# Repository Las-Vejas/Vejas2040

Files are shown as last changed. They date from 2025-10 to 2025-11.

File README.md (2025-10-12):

# Vejas2040
an RP2040 devboard made by me

What it includes:
- RP2040
- 1 Neopixel LED
- 2 buttons
- a pico form factor

Here are some images of the board (3d files):

SCR-20251012-igse
SCR-20251012-igog
SCR-20251012-igli

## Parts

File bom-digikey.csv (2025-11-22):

Manufacturer Part Number | Manufacturer Name | Description | Requested Quantity 1 | Pack Type 1 | Digi-Key Part Number 1 | Unit Price 1 | Total Price | Reference Designator
JMK105BJ105KV-F | Taiyo Yuden | CAP CER 1UF 6.3V X5R 0402 | 10 | Cut Tape (CT) | 587-1231-1-ND | 0.00500 | $0.05 | C1,C10
CL05A104KA5NNNC | Samsung Electro-Mechanics | CAP CER 0.1UF 25V X5R 0402 | 70 | Cut Tape (CT) | 1276-1043-1-ND | 0.00200 | $0.14 | C2,C3,C4,C5,C6,C7,C8,C9,C11,C12,C17,C18
CL10A106MP8NNNC | Samsung Electro-Mechanics | CAP CER 10UF 10V X5R 0603 | 10 | Cut Tape (CT) | 1276-1871-1-ND | 0.01700 | $0.17 | C13,C14
CL05C330JB5NNNC | Samsung Electro-Mechanics | CAP CER 33PF 50V C0G/NP0 0402 | 10 | Cut Tape (CT) | 1276-1272-1-ND | 0.00300 | $0.03 | C15,C16
DX07S016JA1R1500 | JAE Electronics | CONN RCP USB2.0 TYP C 24P SMD RA | 5 | Cut Tape (CT) | 670-DX07S016JA1R1500CT-ND | 1.67000 | $8.35 | J1
ERA-2AEB512X | Panasonic Electronic Components | RES SMD 5.1K OHM 0.1% 1/16W 0402 | 10 | Cut Tape (CT) | P5.1KDCCT-ND | 0.08200 | $0.82 | R1,R2
RC0402FR-0727R4L | YAGEO | RES 27.4 OHM 1% 1/16W 0402 | 10 | Cut Tape (CT) | YAG3085CT-ND | 0.00700 | $0.07 | R3,R4
RC0402JR-071KL | YAGEO | RES 1K OHM 5% 1/16W 0402 | 15 | Cut Tape (CT) | 311-1.0KJRCT-ND | 0.00600 | $0.09 | R5,R7,R8
RC0402JR-0710KL | YAGEO | RES 10K OHM 5% 1/16W 0402 | 10 | Cut Tape (CT) | 311-10KJRCT-ND | 0.00600 | $0.06 | R6
SKRKAHE020 | Alps Alpine | SWITCH TACTILE SPST-NO 0.05A 12V | 10 | Cut Tape (CT) | 4809-SKRKAHE020CT-ND | 0.35100 | $3.51 | SW1,SW2
SC0914(13) | Raspberry Pi | IC MCU 32BIT EXT MEM 56QFN | 5 | Cut Tape (CT) | 2648-SC0914(13)CT-ND | 0.70000 | $3.50 | U1
W25Q128JVSIQ TR | Winbond Electronics | IC FLASH 128MBIT SPI/QUAD 8SOIC | 5 | Cut Tape (CT) | 256-W25Q128JVSIQTRCT-ND | 1.85000 | $9.25 | U3
MCP1700T-3302E/TT | Microchip Technology | IC REG LINEAR 3.3V 250MA SOT23-3 | 5 | Cut Tape (CT) | MCP1700T3302ETTCT-ND | 0.51000 | $2.55 | U4
ABM8-272-T3 | Abracon LLC | CRYSTAL 12.0000MHZ 10PF SMD | 5 | Cut Tape (CT) | 535-ABM8-272-T3CT-ND | 0.66000 | $3.30 | Y1

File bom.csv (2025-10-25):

Item | Price
PCB | $9.10
Digikey | $31.87
JLC Shipping | $18.35
TOTAL | $59.32

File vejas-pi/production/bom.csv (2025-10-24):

Designator | Footprint | Quantity | Value | LCSC Part #
C1, C10 | 0402 | 2 | 1uF
C11, C12, C17, C18, C2, C3, C4, C5, C6, C7, C8, C9 | 0402 | 12 | 0.1uF
C13, C14 | 0603 | 2 | 10uF
C15, C16 | 0402 | 2 | 33pF
D2 | LED_WS2812B-2020_PLCC4_2.0x2.0mm | 1 | WS2812B-2020
J1 | USB_C_Receptacle_JAE_DX07S016JA1R1500 | 1 | USB_C_Receptacle_USB2.0_14P
J2, J3 | PinHeader_1x20_P2.54mm_Vertical | 2 | Conn_01x20_Pin
R1, R2 | 0402 | 2 | 5.1K
R3, R4 | 0402 | 2 | 27.4
R5, R7, R8 | 0402 | 3 | 1K
R6 | 0402 | 1 | 10K
SW1, SW2 | SW_Push_SPST_NO_Alps_SKRK | 2 | SW_Push
U1 | QFN-56-1EP_7x7mm_P0.4mm_EP3.2x3.2mm | 1 | RP2040
U2 | LGA-16_3x3mm_P0.5mm_LayoutBorder3x5y | 1 | LIS3DH
U3 | Winbond_USON-8-1EP_3x2mm_P0.5mm_EP0.2x1.6mm | 1 | W25Q128JVS
U4 | SOT-23 | 1 | MCP1700x-330xxTT
Y1 | Crystal_SMD_3225-4Pin_3.2x2.5mm | 1 | 12MHz

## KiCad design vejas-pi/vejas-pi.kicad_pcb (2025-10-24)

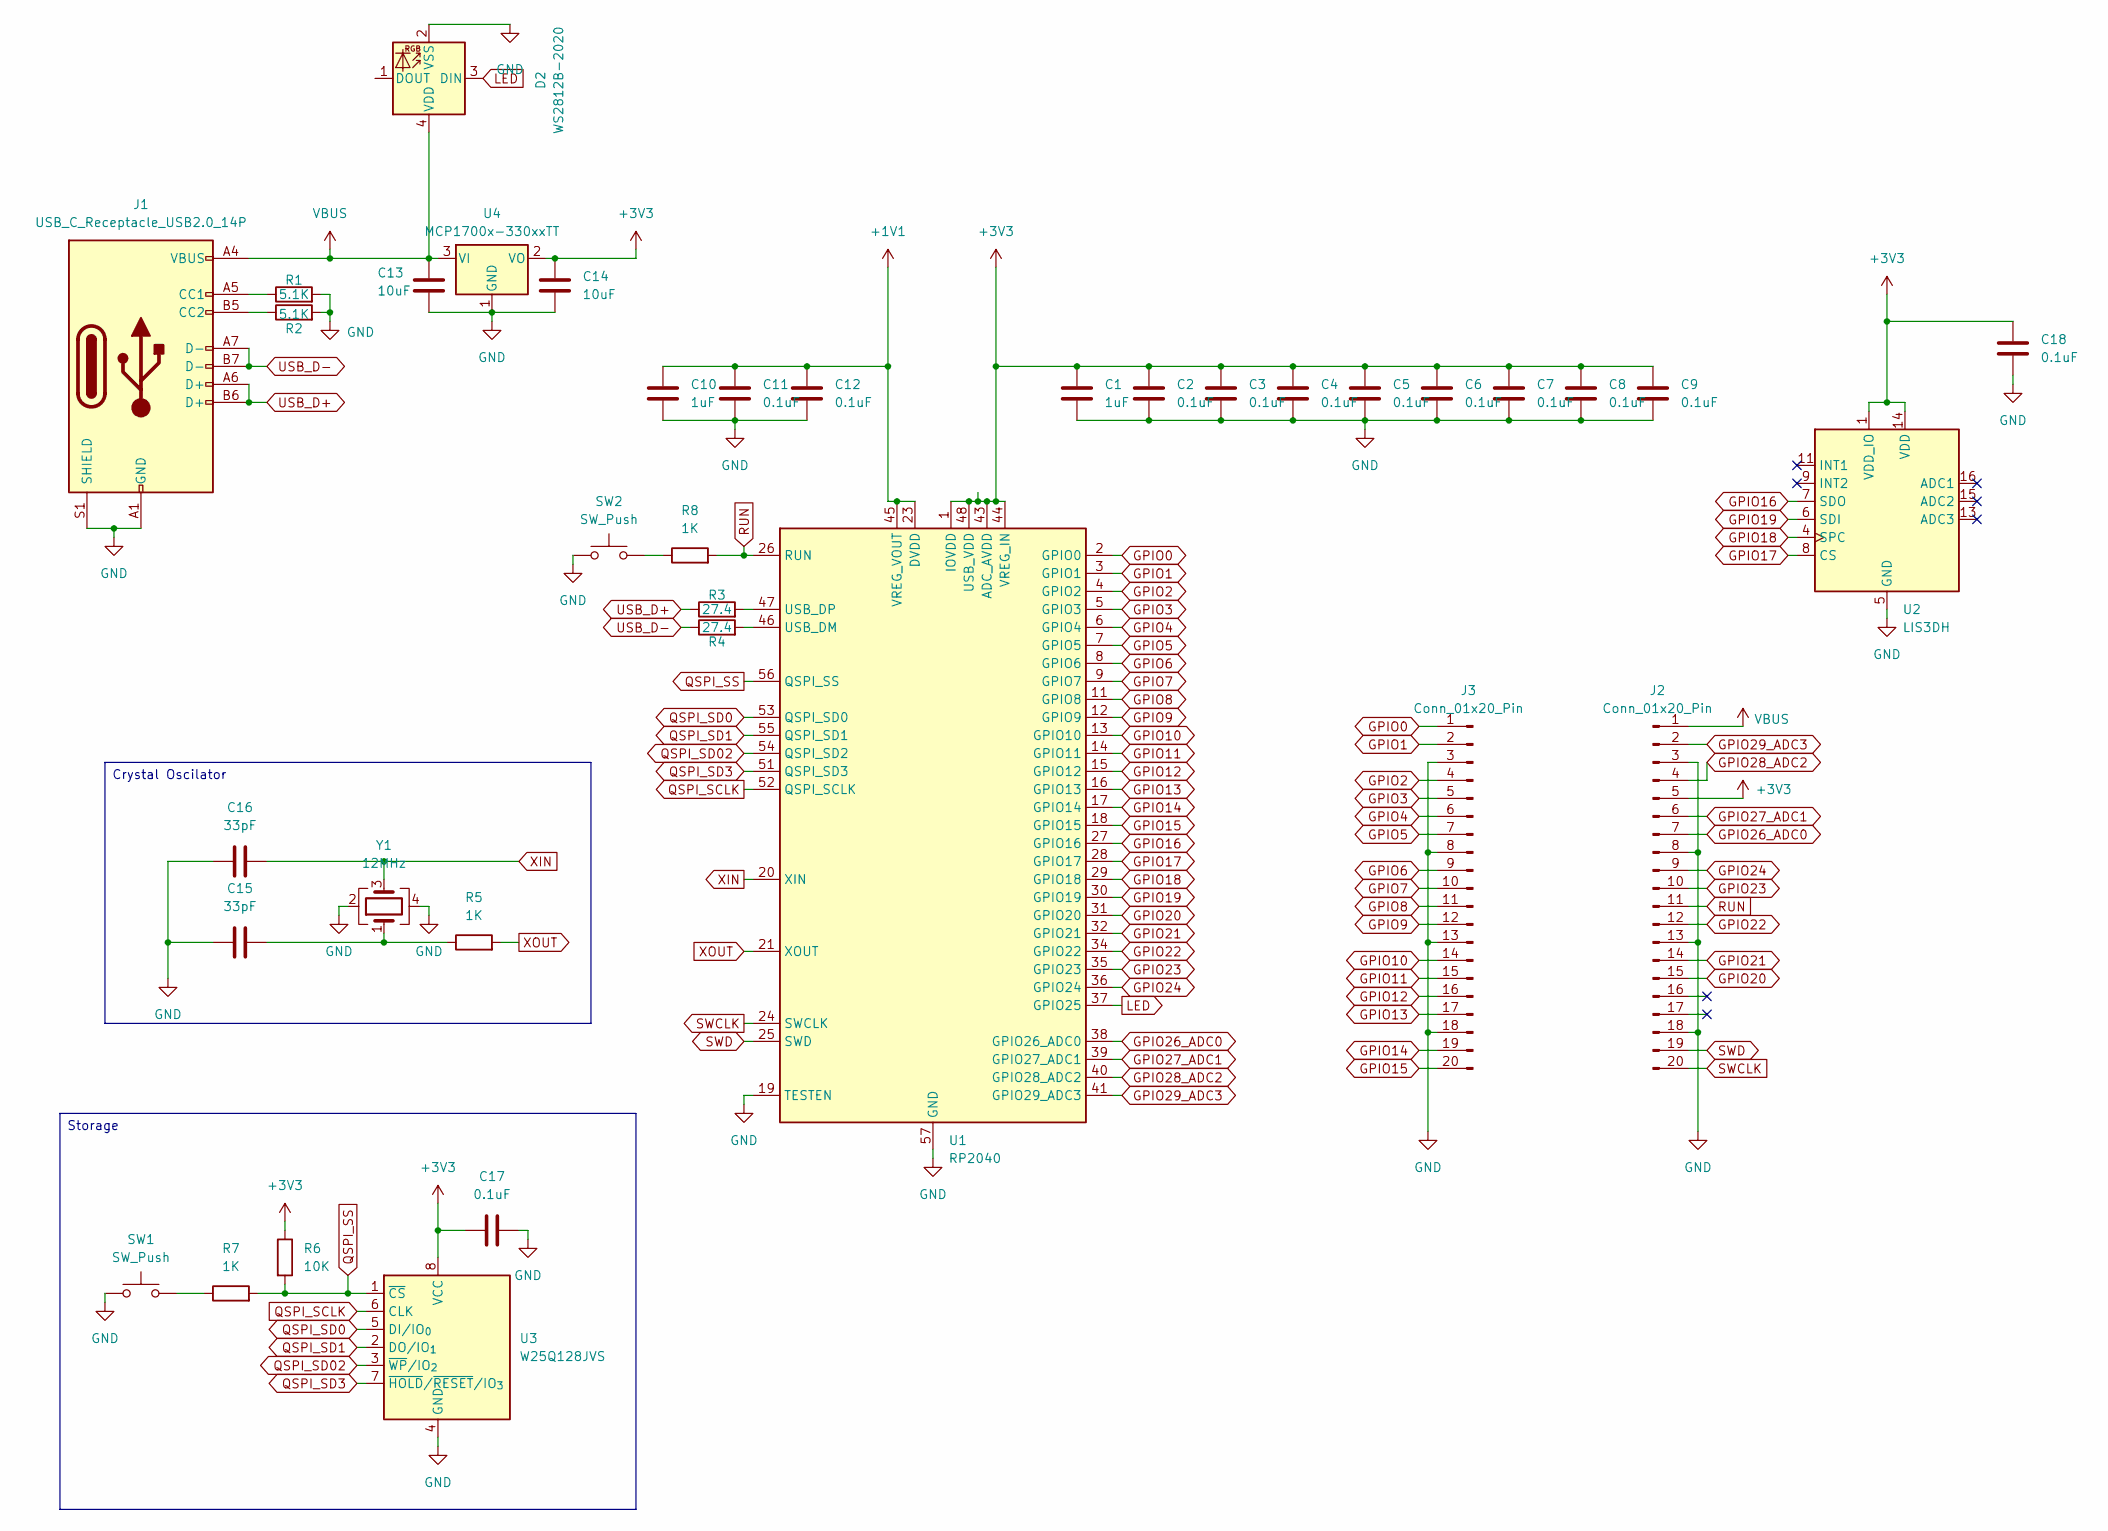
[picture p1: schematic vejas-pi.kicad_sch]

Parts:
C1, C10: 1uF; C_0402_1005Metric
C2, C3, C4, C5, C6, C7, C8, C9, C11, C12, C17, C18: 0.1uF; C_0402_1005Metric
C13, C14: 10uF; C_0603_1608Metric
C15, C16: 33pF; C_0402_1005Metric
D2: WS2812B-2020; LED_WS2812B-2020_PLCC4_2.0x2.0mm
J1: USB_C_Receptacle_USB2.0_14P; USB_C_Receptacle_JAE_DX07S016JA1R1500
J2, J3: Conn_01x20_Pin; PinHeader_1x20_P2.54mm_Vertical
R1, R2: 5.1K; R_0402_1005Metric
R3, R4: 27.4; R_0402_1005Metric
R5, R7, R8: 1K; R_0402_1005Metric
R6: 10K; R_0402_1005Metric
SW1, SW2: SW_Push; SW_Push_SPST_NO_Alps_SKRK
U1: RP2040; QFN-56-1EP_7x7mm_P0.4mm_EP3.2x3.2mm
U2: LIS3DH; LGA-16_3x3mm_P0.5mm_LayoutBorder3x5y
U3: W25Q128JVS; Winbond_USON-8-1EP_3x2mm_P0.5mm_EP0.2x1.6mm
U4: MCP1700x-330xxTT; SOT-23
Y1: 12MHz; Crystal_SMD_3225-4Pin_3.2x2.5mm

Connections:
+1V1: C10.1, C11.1, C12.1, U1.23 (DVDD), U1.45 (VREG_VOUT), U1.50 (DVDD)
+3V3: C1.1, C2.1, C3.1, C4.1, C5.1, C6.1, C7.1, C8.1, C9.1, C14.1, C17.1, C18.1, J2.5, R6.1, U1.1 (IOVDD), U1.10 (IOVDD), U1.22 (IOVDD), U1.33 (IOVDD), U1.42 (IOVDD), U1.43 (ADC_AVDD), U1.44 (VREG_IN), U1.48 (USB_VDD), U1.49 (IOVDD), U2.1 (VDD_IO), U2.14 (VDD), U3.8 (VCC), U4.2 (VO)
GND: C1.2, C2.2, C3.2, C4.2, C5.2, C6.2, C7.2, C8.2, C9.2, C10.2, C11.2, C12.2, C13.2, C14.2, C15.1, C16.1, C17.2, C18.2, D2.2 (VSS), J1.A1 (GND), J1.A12 (GND), J1.B1 (GND), J1.B12 (GND), J1.S1 (SHIELD), J2.3, J2.8, J2.13, J2.18, J3.3, J3.8, J3.13, J3.18, R1.2, R2.2, SW1.1, SW2.1, U1.19 (TESTEN), U1.57 (GND), U2.5 (GND), U2.10 (GND), U2.12 (GND), U3.4 (GND), U4.1 (GND), Y1.2, Y1.4
GPIO0: J3.1, U1.2 (GPIO0)
GPIO1: J3.2, U1.3 (GPIO1)
GPIO2: J3.4, U1.4 (GPIO2)
GPIO3: J3.5, U1.5 (GPIO3)
GPIO4: J3.6, U1.6 (GPIO4)
GPIO5: J3.7, U1.7 (GPIO5)
GPIO6: J3.9, U1.8 (GPIO6)
GPIO7: J3.10, U1.9 (GPIO7)
GPIO8: J3.11, U1.11 (GPIO8)
GPIO9: J3.12, U1.12 (GPIO9)
GPIO10: J3.14, U1.13 (GPIO10)
GPIO11: J3.15, U1.14 (GPIO11)
GPIO12: J3.16, U1.15 (GPIO12)
GPIO13: J3.17, U1.16 (GPIO13)
GPIO14: J3.19, U1.17 (GPIO14)
GPIO15: J3.20, U1.18 (GPIO15)
GPIO16: U1.27 (GPIO16), U2.7 (SDO)
GPIO17: U1.28 (GPIO17), U2.8 (CS)
GPIO18: U1.29 (GPIO18), U2.4 (SPC)
GPIO19: U1.30 (GPIO19), U2.6 (SDI)
GPIO20: J2.15, U1.31 (GPIO20)
GPIO21: J2.14, U1.32 (GPIO21)
GPIO22: J2.12, U1.34 (GPIO22)
GPIO23: J2.10, U1.35 (GPIO23)
GPIO24: J2.9, U1.36 (GPIO24)
GPIO26_ADC0: J2.7, U1.38 (GPIO26_ADC0)
GPIO27_ADC1: J2.6, U1.39 (GPIO27_ADC1)
GPIO28_ADC2: J2.4, U1.40 (GPIO28_ADC2)
GPIO29_ADC3: J2.2, U1.41 (GPIO29_ADC3)
LED: D2.3 (DIN), U1.37 (GPIO25)
unnamed: C15.2, R5.1, Y1.1
unnamed: J1.A5 (CC1), R1.1
unnamed: J1.B5 (CC2), R2.1
unnamed: R7.1, SW1.2
unnamed: R8.1, SW2.2
unnamed: R4.2, U1.46 (USB_DM)
unnamed: R3.2, U1.47 (USB_DP)
QSPI_SCLK: U1.52 (QSPI_SCLK), U3.6 (CLK)
QSPI_SD0: U1.53 (QSPI_SD0), U3.5 (DI/IO_{0})
QSPI_SD1: U1.55 (QSPI_SD1), U3.2 (DO/IO_{1})
QSPI_SD02: U1.54 (QSPI_SD2), U3.3 (~WP/IO_{2})
QSPI_SD3: U1.51 (QSPI_SD3), U3.7 (~HOLD/~RESET/IO_{3})
QSPI_SS: R6.2, R7.2, U1.56 (QSPI_SS), U3.1 (~CS)
RUN: J2.11, R8.2, U1.26 (RUN)
SWCLK: J2.20, U1.24 (SWCLK)
SWD: J2.19, U1.25 (SWD)
USB_D+: J1.A6 (D+), J1.B6 (D+), R3.1
USB_D-: J1.A7 (D-), J1.B7 (D-), R4.1
VBUS: C13.1, D2.4 (VDD), J1.A4 (VBUS), J1.A9 (VBUS), J1.B4 (VBUS), J1.B9 (VBUS), J2.1, U4.3 (VI)
XIN: C16.2, U1.20 (XIN), Y1.3
XOUT: R5.2, U1.21 (XOUT)

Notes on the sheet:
Crystal Oscilator
Storage

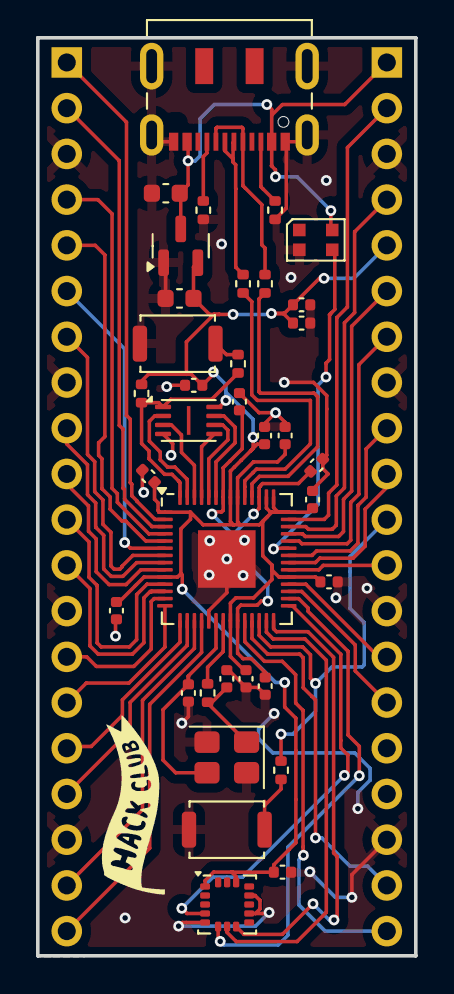
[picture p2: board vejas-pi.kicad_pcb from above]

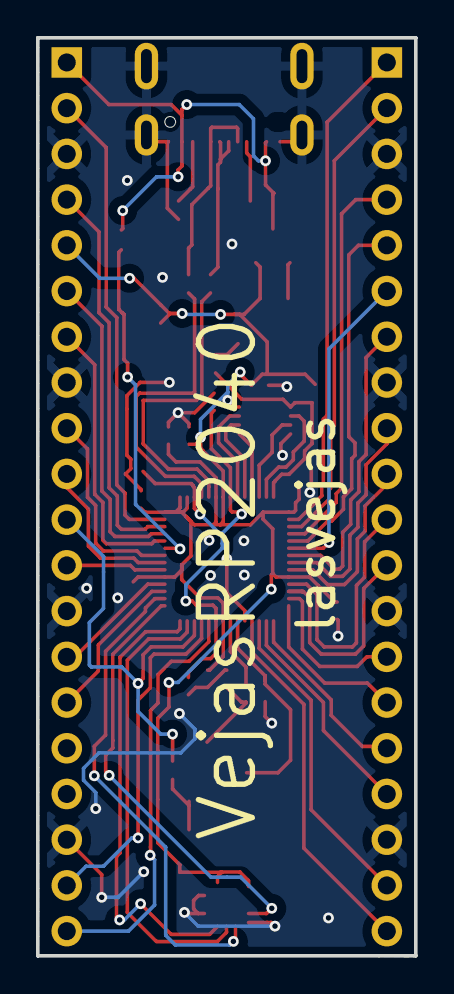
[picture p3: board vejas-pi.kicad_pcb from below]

Board: 2 copper layers, 21.0 x 51.0 mm, 37 parts (2 on the bottom side), 54 nets.

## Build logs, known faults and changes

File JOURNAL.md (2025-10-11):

<!--
  ===================    !!READ THIS NOTICE!!   ====================
  DO NOT edit this file manually. Your changes WILL BE OVERWRITTEN!
  This journal is auto generated and updated by Hack Club Blueprint.
  To edit this file, please edit your journal entries on Blueprint.
  ==================================================================
-->

This is my journal of the design and building process of **vejas2040**.  
You can view this journal in more detail on **Hack Club Blueprint** [here](https://blueprint.hackclub.com/projects/191).

## 10/5/2025 - Made the schematic and added parts onto PCB.  

I have decided to make a dev board even though I have no clue on what im doing. :sob: 
I am following the guide, and I have added all the parts on my schematic and my PCB.

Here is what my PCB looks like right now:


I have no clue where to put the capacitors but ill try my best.

Here is what my schematic looks like:


## 10/10/2025 - ReRouted the PCB  

So my routing was a mess. I rerouted and now (not fully done) im feeling (and it's looking) much better. It looks much more like an octopus branching out its tentacles. Find images below.





My next steps are going to be to add a reset button and an rbg led. I might use this as a pico alt for keyboard builds in the future.   

## 10/11/2025 - Finished the pcb and jlc  

So I finished routing the pcb. I added the neopixel (which I will have to buy and add separately, as PCBA for it would cost a fortune) and a reset button. Im planning to solder the neopixel at school as I think there may be a hotplate somewhere there. 
The whole PCB is now finished and the project is done. 





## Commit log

2025-10-05 git init
    added kicad files
    [vejas-pi.kicad_pcb, vejas-pi.kicad_sch]
2025-10-11 a lot of pcb
    [vejas-pi.kicad_pcb, vejas-pi.kicad_sch]
2025-10-11 pcb v1
    [vejas-pi.kicad_pcb, vejas-pi.kicad_sch]
2025-10-12 Add images of the board to README
    Added images of the board to the README.
2025-10-17 very kul
    [vejas-pi.kicad_pcb, vejas-pi.kicad_sch]
2025-10-24 cool stuff V1.1 SHIPPED
    [bom-digikey.csv, bom.csv, designators.csv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]
2025-10-25 Update BOM format and item prices
    [bom.csv]
2025-11-22 Fix header row in bom-digikey.csv
    Updated the header row in the BOM CSV file to include the correct column names.
    [bom-digikey.csv]
2025-11-22 Change BOM delimiter from semicolon to comma
    Updated the BOM format to use commas instead of semicolons for better compatibility.
    [bom-digikey.csv]
2025-11-22 Fix BOM header formatting in bom-digikey.csv
    [bom-digikey.csv]
2025-11-22 Fix CSV: remove extra header and quote reference designators
    [bom-digikey.csv]
